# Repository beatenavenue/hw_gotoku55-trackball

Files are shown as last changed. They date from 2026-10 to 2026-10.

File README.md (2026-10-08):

English | [日本語](README_ja.md)

> They say the trackball journey ends once you buy a Kensington SlimBlade Pro and an Elecom COMFY wrist rest.  
> But couldn't the case be made smaller?

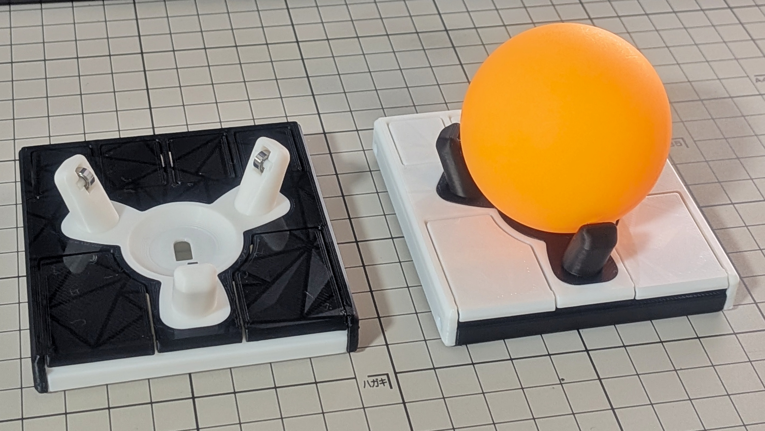
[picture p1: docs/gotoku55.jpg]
overview


# GOTOKU-55 Trackball

## What is this?
This is a **part** for a 55 mm trackball. To see where it fits, you need some background, in order.

### Ploopy Adept
The Adept is a trackball with a 44 mm ball (1.75 in ≈ 44.5 mm), developed by Ploopy, a small Canadian company. The design files and firmware are open source, but parts you source yourself may not fit dimensionally, so buying a kit or a fully assembled unit from the official Ploopy store is recommended.

- Link: [Adept Trackball](https://ploopy.co/adept-trackball/)

### Anyball
Adept Anyball is a mod project that reworks the Adept case so that the ball rides on BTUs (ball transfer units). By choosing a case variant, you can use anything from a small 34 mm ball up to a 68 mm billiard ball. The files are published on GitHub, and you 3D print and assemble them yourself.

There is of course a 55 mm version, but its supports sit low, so the ball sticks far out of the case and it is not very comfortable to use.

- Link: [Adept Anyball](https://github.com/adept-anyball/)

### small-btu v4 (Slim)
A compact case for 34 mm / 38 mm balls by Fabricio Bastian, published within the Anyball project. It is made as low-profile as possible so that it can sit between the halves of a split keyboard, and its design is beautiful and refined.  
Going by the height of the buttons alone, it is probably lower than the Keychron Nape Pro, one of the smallest trackballs on the market. If you like low-profile keyboards, it is very appealing.

- Link: [adept-anyball/ploopy-adept-small-btu](https://github.com/adept-anyball/ploopy-adept-small-btu)

### GOTOKU-55
Putting a 55 mm ball on small-btu v4 is quite a stretch. The ball itself is large, and arms built for BTUs become huge as well, so it would be almost unusable.  
So, to keep things compact, I made an arm part (the "trackball support" in small-btu terms) that holds a 55 mm ball on the same ball bearings Ploopy uses. That is GOTOKU-55. The name comes from *gotoku* (五徳), the pronged trivet that holds a pot over a Japanese gas burner, which is what the arm part looks like. The 55 is the ball diameter in millimetres.

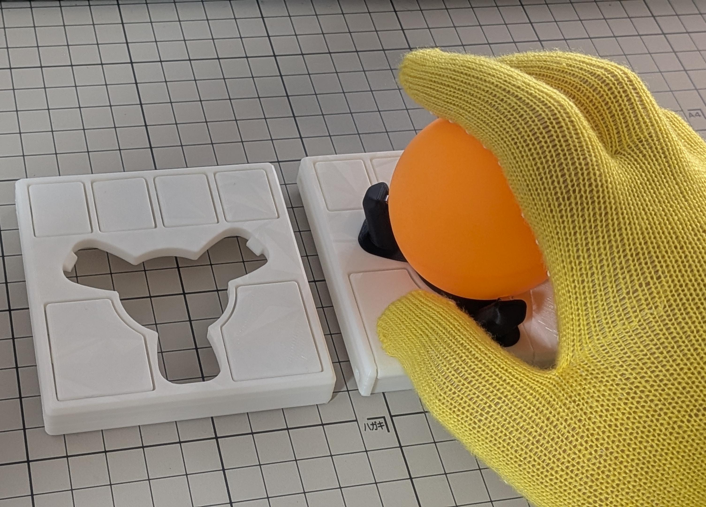
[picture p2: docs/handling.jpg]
handling


In most cases the arm part is all you need. The small-btu v4 case is polished and beautiful, so you can use it as is.  
However, with a grip like mine, the stock v4 gets in the way: when I lay my thumb flat to press the front buttons, the corner of the case hits my finger.

So, for people who hold it this way, I also made a modified version that extends the front buttons all the way to the edge.  
The screw holes and so on are unchanged from v4, so printing only the top is enough, but the front wall disappears and it looks a little bare, so I made a bottom as well.

## Compatibility
small-btu v4 only.

v5 has a similar shape, so it might work, but by my estimate the ball would probably interfere slightly.

## How to build
See the [build guide](docs/BUILD.md).

## License
Copyright (C) 2026 Kotaro WAJIKI  
Based on ploopy-adept-small-btu v4, Copyright (C) Fabricio Bastian  
Licensed under the GNU General Public License v3.0

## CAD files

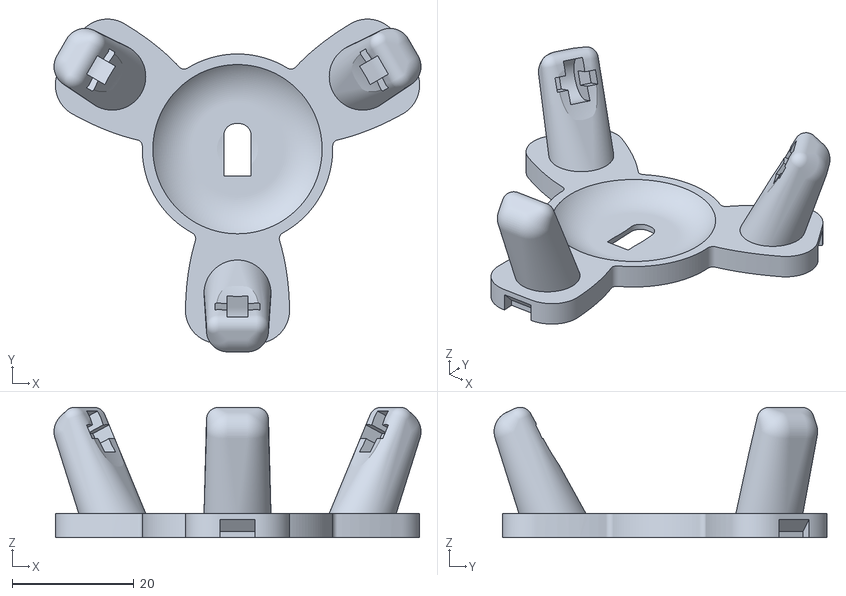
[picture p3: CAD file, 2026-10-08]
3d-model/v4-slim-55mm-smr63-65deg-rounded-trackball-support.stl
60.3 x 54.7 x 21.4

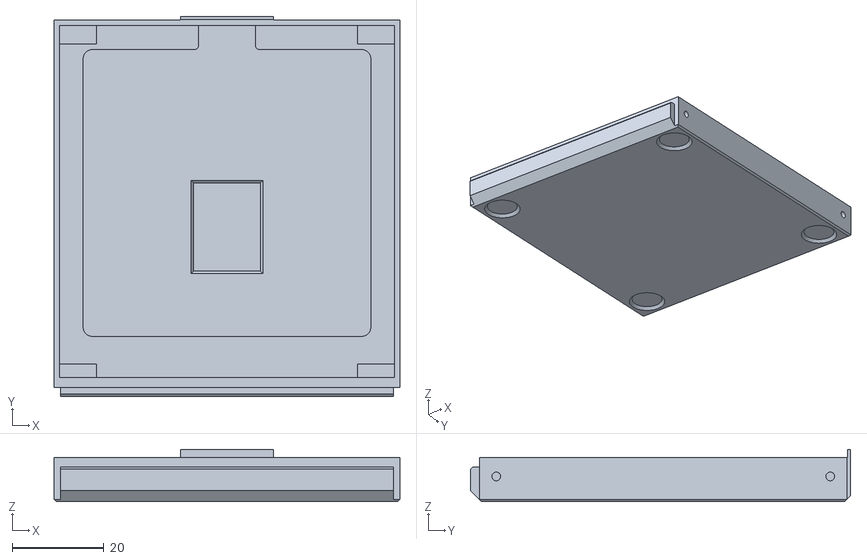
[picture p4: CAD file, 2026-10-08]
3d-model/gotoku-v4-slim-bottom.stl
75.2 x 82.7 x 11.4

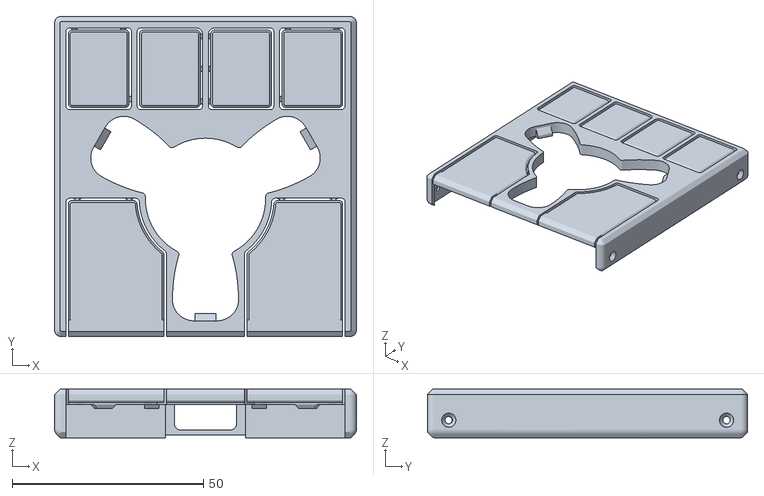
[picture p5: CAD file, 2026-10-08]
3d-model/gotoku-v4-slim-top.stl
79.0 x 83.8 x 12.7

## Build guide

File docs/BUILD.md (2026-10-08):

English | [日本語](BUILD_ja.md)

# Building GOTOKU-55

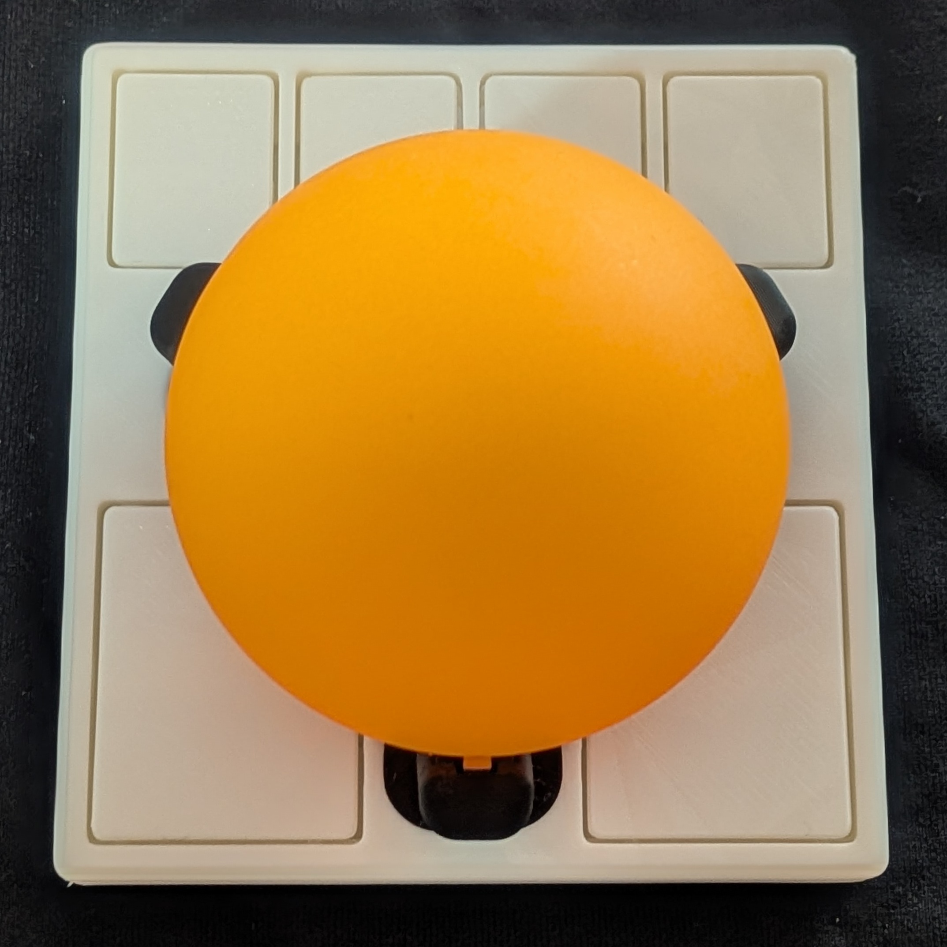
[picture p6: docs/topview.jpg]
top


## Parts needed

### Electronics
- [Ploopy Adept PCB](https://github.com/ploopyco/adept-trackball/tree/master/hardware/electronics)
- [Firmware](https://github.com/ploopyco/qmk_firmware)
- PMW3360 optical sensor
  - LM19-LSI lens
- USB-C cable

Buying the Adept kit gets you all of the electronics.

### Mechanical parts
- 55 mm ball
- M2x10mm countersunk screws x4
- SMR63ZZ ball bearings x3

If you hesitate to buy an expensive 55 mm ball right away, a 55 mm table tennis practice ball is a cheap alternative.

Ball bearings rust quickly unless they are stainless steel. I recommend NSK ones.

### 3D printed parts
- [Bearing dowel (axle)](https://github.com/ploopyco/classic-2-trackball/tree/master/hardware/mechanicals)
- [Bearing press jig](https://github.com/ploopyco/classic-2-trackball/tree/master/hardware/mechanicals)
- [GOTOKU arm](../3d-model/)
- Case top
  - [small-btu v4 case top](https://github.com/adept-anyball/ploopy-adept-small-btu/tree/main/v4)
  - [GOTOKU case top](../3d-model/)
- Case bottom
  - [small-btu v4 case bottom](https://github.com/adept-anyball/ploopy-adept-small-btu/tree/main/v4)
  - [GOTOKU case bottom](../3d-model/)

The parts must be printed in the right orientation. As a rule, the large flat face goes on the build plate.

## Assembly

### Assembling the bearings
Use the jig to press a dowel into each bearing. It probably makes no difference in practice if the dowel is not perfectly centered.

Press the bearings into the GOTOKU arm part. The jig is handy for this. Once they are in, check that they spin smoothly.

If something goes wrong, insert a precision screwdriver or similar through the gap and push the bearing out from behind to start over.

### Assembling the case
Fit the GOTOKU arm into the case top.

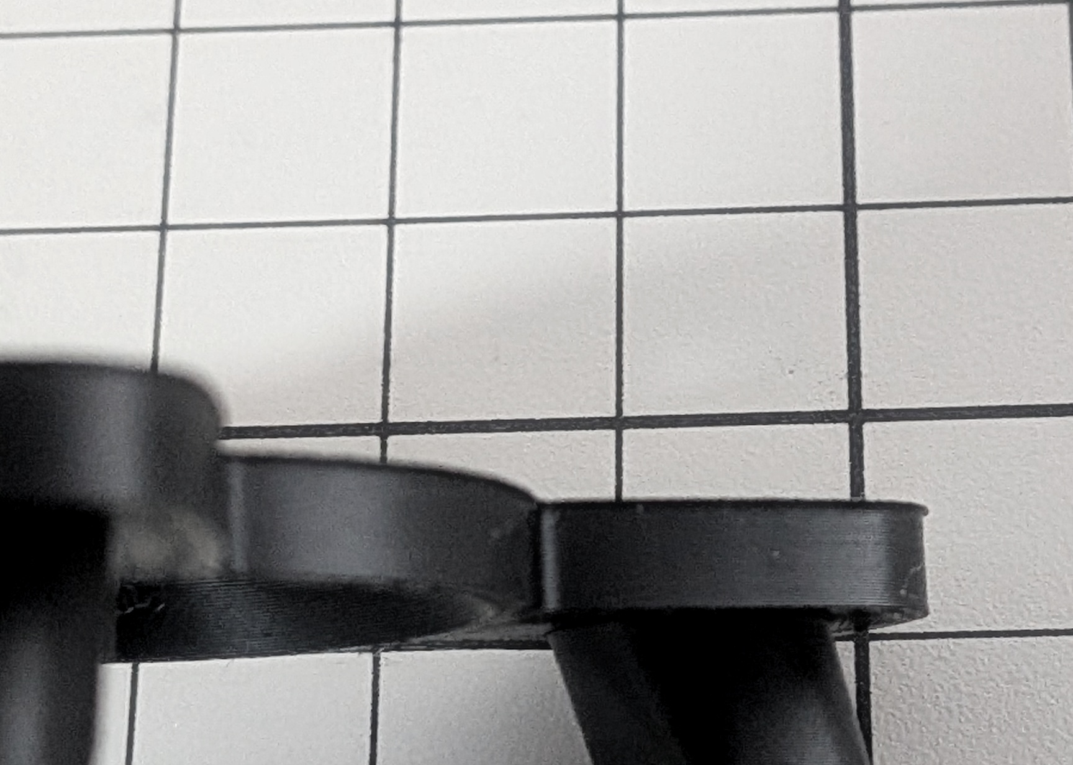
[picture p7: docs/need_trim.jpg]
trim


If the fit is tight, check whether the bottom face of the print has flared out into a thin lip. You may need to trim it a little with a file or a knife.

If the ball does not track or the buttons do not press properly, the case may need adjusting.
3D printed parts are not strong enough to be screwed together many times, so test that everything works before you drive the screws in.

### Sharing your build
An expensive trackball ball may reflect your room, or your face.
Check before you post photos of your trackball on social media.

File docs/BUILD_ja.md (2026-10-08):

[English](BUILD.md) | 日本語

# GOTOKU-55 のつくりかた

top

## 必要なパーツ

### 電子部品
- [Ploopy Adept PCB](https://github.com/ploopyco/adept-trackball/tree/master/hardware/electronics)
- [ファームウェア](https://github.com/ploopyco/qmk_firmware)
- PMW3360 光学センサ
  - LM19-LSI レンズ
- USB-Cケーブル

電子部品についてはAdeptのキットを買えば揃います。

### 機械部品
- 55mm球
- M2x10mm 皿ネジ x4
- SMR63ZZ ボールベアリング x3

いきなり高価な55mm球を買うのを躊躇する場合は55mmの卓球練習用ボールが安価です。

ボールベアリングはステンレス製でないとすぐ錆びます。日本精工製がおすすめです。

### 3Dプリント品
- [ベアリング軸](https://github.com/ploopyco/classic-2-trackball/tree/master/hardware/mechanicals)
- [ベアリングはめこみ治具](https://github.com/ploopyco/classic-2-trackball/tree/master/hardware/mechanicals)
- [GOTOKU 腕](../3d-model/)
- 筐体トップ
  - [small-btu v4 筐体トップ](https://github.com/adept-anyball/ploopy-adept-small-btu/tree/main/v4)
  - [GOTOKU 筐体トップ](../3d-model/)
- 筐体ボトム
  - [small-btu v4 筐体ボトム](https://github.com/adept-anyball/ploopy-adept-small-btu/tree/main/v4)
  - [GOTOKU 筐体ボトム](../3d-model/)

3Dプリントは適切な向きで行う必要があります。基本的に大きな平面がプレート側です。

## 組立手順

### ベアリングの組立
治具を使ってベアリングに軸を押し込みます。このとき完全に中央に位置していなくても動作上おそらく影響はないです。

GOTOKU腕パーツにベアリングを押し込みます。押し込みには治具を使うと便利です。押し込んだ後滑らかに回転することを確認してください。

もし失敗した場合は精密ドライバーなどを隙間から差し込み、ベアリングを後ろから押し出せばやり直せます。

### ケースの組立
筐体トップにGOTOKU腕をはめ込みます。

trim

嵌合がきつい場合はプリント時に底面が薄く突き出していないか確認してください。少しヤスリやカッターで整える必要があるかもしれません。

ボールの読み取りやボタンの押下に問題があればケースの調整が必要かもしれません。
3Dプリント品は何度もネジ止めできるほど強度が高くないのでネジ止め前に動作確認をしておきましょう。

### 結果報告
高価なトラックボール球は部屋の風景やあなたの顔が映り込む可能性があります。
SNSなどに製作したトラックボールの写真を投稿する際は事前に確認しておきましょう。

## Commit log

2026-10-08 first version.
    [gotoku-v4-slim-bottom.stl, gotoku-v4-slim-top.stl, v4-slim-55mm-smr63-65deg-rounded-trackball-support.stl]
2026-10-11 Update GOTOKU arm to the buttress version
    Replace the 65deg arm with the latest GOTOKU arm.
    - The flat base and the inner faces of the three arms are unchanged.
    - Each arm now has a buttress on its outer side. It comes down almost
    vertically and rests on the case top deck, 2 mm past the insert edge.
    This reduces the outward spread of the arms under a heavy ball.
    - The footprint stays at least 3.7 mm away from every button pad.
    - Rename the file to match the gotoku- prefix of the case parts.
    Claude-Session: https://claude.ai/code/session_018NHmFHhEtXMLckUM191uXM
2026-10-11 Add assembled STL with a 55 mm ball
    Add a preview model that combines the case top, the case bottom,
    the 65deg arm and a 55 mm ball in their assembled positions.
    GitHub shows STL files in an interactive 3D viewer, so visitors can
    see how far the ball reaches over the buttons.
    This file is for viewing only. It is not meant for printing.
    The bearings are not included.
    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
2026-10-24 Release GOTOKU-55 arm and case versions
    Arm (final design, CadQuery B-rep, STEP + STL):
    - One-piece version for PLA printing.
    - Split version for SLM metal printing: metal arm + PLA center floor.
    The floor goes in from below and is held between the arm and the
    sensor lens.
    - Each post has a 3 mm push-out hole for a toothpick.
    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
2026-10-28 Remove the vertical screw case and simplify the docs
    The vertical screw case was made so that the bottom case could be
    printed in metal without tapping. The metal printing review showed that
    a metal bottom is not practical for this slim case. So the vertical
    screw version is removed, and only the side screw case remains.
    - Delete the vertical screw top (STL) and bottom (STEP, STL).
    - Rebuild the assembled STL with the side screw case.
    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
2026-10-30 Shorten the 3D model file names
    The old names listed attributes that no longer tell the files apart.
    There is only one bearing (SMR63) and one support angle (65 deg), the
    vertical screw case was removed so "side-screw" is not needed, and "55mm"
    repeats the 55 in GOTOKU-55. The new names use the same words as the docs
    (arm, floor, case).
    - gotoku-v4-slim-55mm-smr63-65deg-trackball-support -> gotoku55-arm
    - ...-trackball-support-split-metal -> gotoku55-arm-split-metal
    - ...-trackball-support-split-floor-disc -> gotoku55-arm-split-floor
    - gotoku-v4-slim-top-side-screw -> gotoku55-case-top
    - gotoku-v4-slim-bottom-side-screw -> gotoku55-case-bottom
    - gotoku-v4-slim-assembled-with-55mm-ball -> go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
2026-10-30 add button plus
